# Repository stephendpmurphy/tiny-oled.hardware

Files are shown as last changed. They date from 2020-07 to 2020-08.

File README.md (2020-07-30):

# ATtiny OLED

## Description
This project is intended to challenge myself and be used as a way to explore and try new concepts in electrical hardware design. The current planned challenges are as follows
- Design and maintain a full PCB in KiCad
- Use 0402 components as much as possible (my current standard is 0603)
- Create a board that is easily testable and probe friendly (test pads galore)
- Add a 128x64 OLED driver and connector
- Add a coin-cell battery holder
- Add side-fire push-buttons for the UI
- Add I2c addressable RGB LEDs
- Add a SD card using a SPI interface to the host MCU
- Focus on low power consumption to preserve battery life
- Add FTDI bridge to give USB connectivity to the host MCU over UART

## Hardware
For this project I will be using an [ATtiny87 from Atmel/Microchip](https://www.microchip.com/wwwproducts/en/ATTINY87). The part has a limited feature set and a small amount of memory, but hopefully enough to implement everything desired and provide an adequate challenge. 
- 8KB of Flash
- 512B or SRAM
- 512B of EEPROM
- 1x UART
- 2x SPI
- 1x I2c

The project for the firmware can be found in the [tiny-oled.firmware](https://github.com/stephendpmurphy/tiny-oled.firmware) repository on my profile. The project will be created and managed using the open source electrical design suite, [KiCad](https://kicad-pcb.org/).

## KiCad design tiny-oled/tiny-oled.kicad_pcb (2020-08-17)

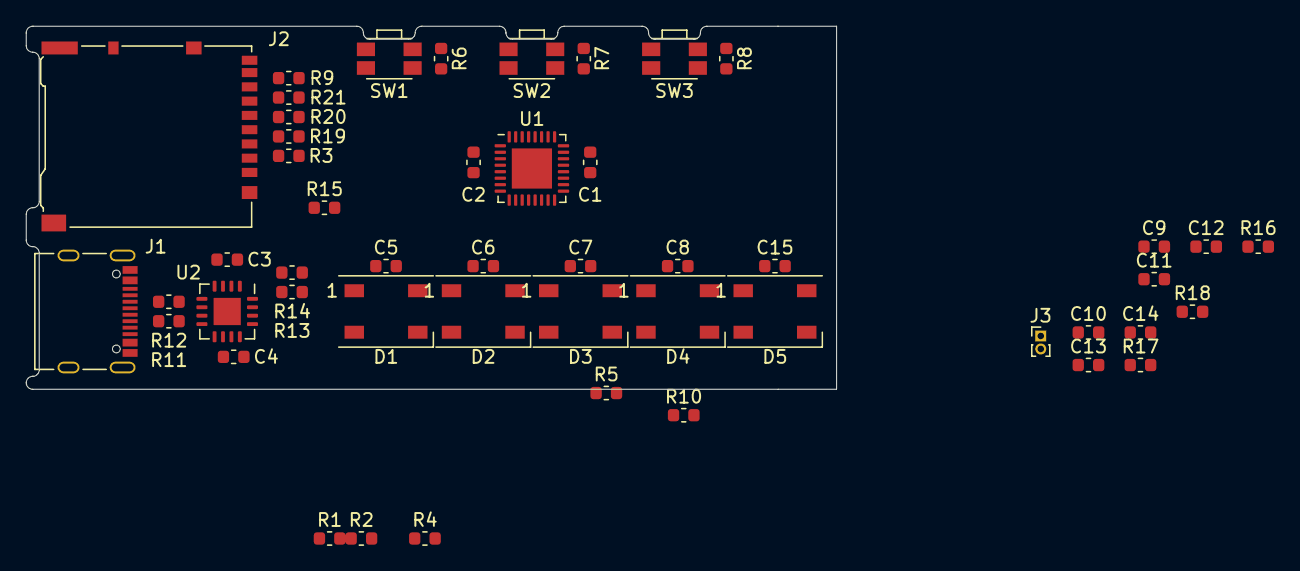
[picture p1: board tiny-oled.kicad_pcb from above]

Board: 2 copper layers, 62.5 x 28.0 mm, 49 parts (0 on the bottom side), 35 nets, no tracks yet.

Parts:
C1, C2, C3, C4, C5, C6, C7, C8, C15: .1uF; C_0603_1608Metric
C9, C10, C12, C14: 1uF; C_0603_1608Metric
C11, C13: 10uF; C_0603_1608Metric
D1, D2, D3, D4, D5: WS2812B; LED_WS2812B_PLCC4_5.0x5.0mm_P3.2mm
J1: USB4085-GF-A; USB_C_Receptacle_Palconn_UTC16-G
J2: Micro_SD_Card_Det_Hirose_DM3AT; microSD_HC_Hirose_DM3AT-SF-PEJM5
J3: F32Q-1A7H1-11015; PinHeader_1x02_P1.00mm_Vertical
R1, R2, R3, R4, R5, R6, R7, R8, R9, R10: 10k; R_0603_1608Metric
R11, R12: 27; R_0603_1608Metric
R13, R14, R17, R18, R19, R20, R21: 0; R_0603_1608Metric
R15: 470; R_0603_1608Metric
R16: 560k; R_0603_1608Metric
SW1, SW2, SW3: EVQP7A; SW_SPST_EVQP7A
U1: ATtiny87-MU; QFN-32-1EP_5x5mm_P0.5mm_EP3.1x3.1mm
U2: FT230XQ; QFN-16-1EP_4x4mm_P0.65mm_EP2.1x2.1mm

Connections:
GND: C1.2, C2.2, C3.2, C4.2, C5.2, C6.2, C7.2, C8.2, C9.2, C10.2, C11.2, C13.2, C15.2, D1.3, D2.3, D3.3, D4.3, D5.3, J1.A1, J1.A12, J1.B1, J1.B12, J1.S1, J2.6, J2.9, J2.11, R16.2, SW1.2, SW2.2, SW3.2, U1.5, U1.21, U1.33, U2.3, U2.13, U2.17
unnamed: C14.1, J3.1
unnamed: C14.2, J3.2
unnamed: D1.2, D2.4
unnamed: D1.4, R15.1
unnamed: D2.2, D3.4
unnamed: D3.2, D4.4
unnamed: D4.2, D5.4
unnamed: J1.A6, J1.B6, R12.2
unnamed: J1.A7, J1.B7, R11.2
unnamed: J2.3, R19.1
unnamed: J2.5, R20.1
unnamed: J2.7, R21.1
unnamed: R13.2, U2.15
unnamed: R14.1, U2.2
SPI_MISO: R21.2, U1.31
SPI_MOSI: R18.2, R19.2, U1.9
SPI_SCK: R17.2, R20.2, U1.10
SSD1306_DC: R5.2, U1.12
UART_RX: R13.1, U1.30
UART_TX: R14.2, U1.29
USB_DM: R11.1, U2.7
USB_DP: R12.1, U2.6
USB_VBUS: J1.A4, J1.A9, J1.B4, J1.B9
VCC: C1.1, C2.1, C3.1, C4.1, C5.1, C6.1, C7.1, C8.1, C9.1, C10.1, C15.1, D1.1, D2.1, D3.1, D4.1, D5.1, J2.4, R1.1, R2.1, R3.1, R4.1, R5.1, R6.1, R7.1, R8.1, R9.1, R10.1, U1.4, U1.20, U2.1, U2.10
WS2812_DO: R15.2, U1.15
~BTN1: R6.2, SW1.1, U1.28
~BTN2: R7.2, SW2.1, U1.27
~BTN3: R8.2, SW3.1, U1.26
~RESET: R10.2, U1.14, U2.9
~SD_DETECT: J2.10, R9.2, U1.25
~SPI_CS_BME280: R2.2, U1.18
~SPI_CS_SD: J2.2, R3.2, U1.3
~SPI_CS_SSD1306: R1.2, U1.19
~SSD1306_RESET: R4.2, U1.11
